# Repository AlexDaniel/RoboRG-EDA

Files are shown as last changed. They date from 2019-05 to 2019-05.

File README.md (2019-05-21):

# RoboRG-EDA

Schematics and PCB design files.



## License

    RoboRG is a low-cost camera motion control system.
    Copyright © 2018-2019
        Aleks-Daniel Jakimenko-Aleksejev <alex.jakimenko@gmail.com>

    This program is free software: you can redistribute it and/or modify
    it under the terms of the GNU Affero General Public License as
    published by the Free Software Foundation, either version 3 of the
    License, or (at your option) any later version.

    This program is distributed in the hope that it will be useful,
    but WITHOUT ANY WARRANTY; without even the implied warranty of
    MERCHANTABILITY or FITNESS FOR A PARTICULAR PURPOSE.  See the
    GNU Affero General Public License for more details.

    You should have received a copy of the GNU Affero General Public License
    along with this program.  If not, see <https://www.gnu.org/licenses/>.

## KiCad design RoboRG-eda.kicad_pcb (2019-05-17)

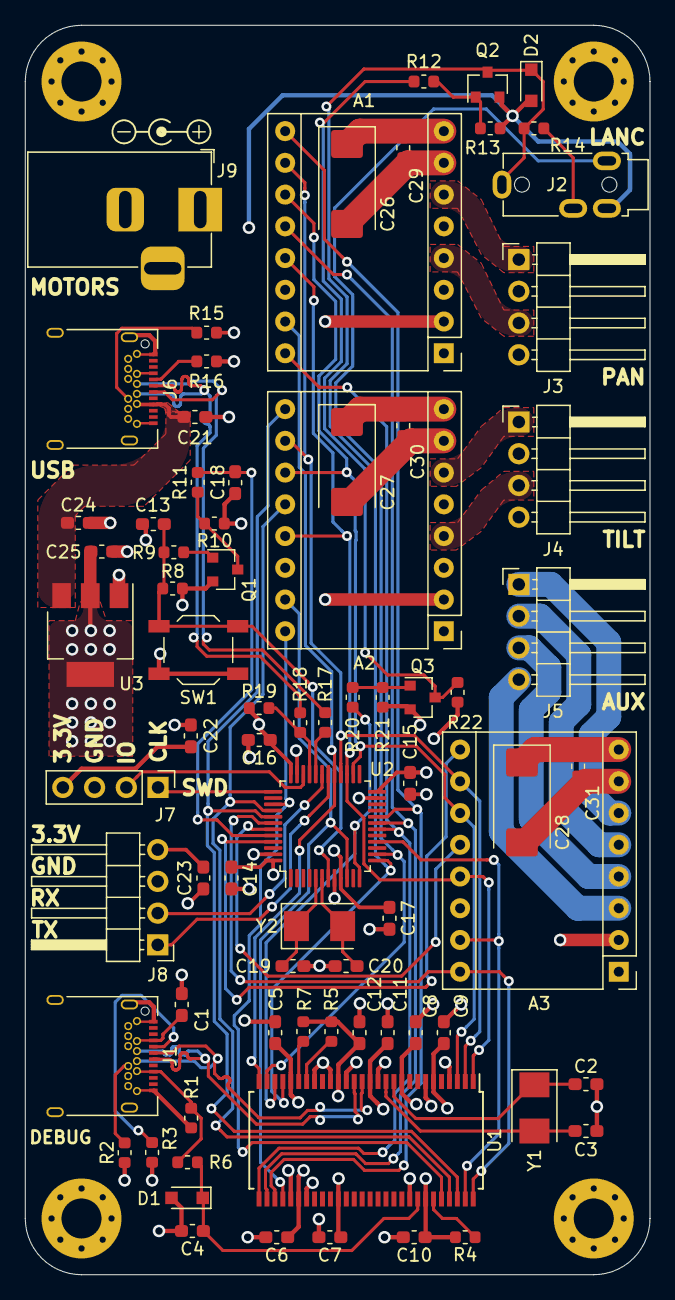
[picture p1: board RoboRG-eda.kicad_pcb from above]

Board: 4 copper layers, 50.0 x 100.0 mm, 80 parts (0 on the bottom side), 65 nets.

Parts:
A1: driver-pan (TMC2130); Pololu_Breakout-16_15.2x20.3mm
A2: driver-tilt (TMC2130); Pololu_Breakout-16_15.2x20.3mm
A3: driver-other (TMC2130); Pololu_Breakout-16_15.2x20.3mm
C1, C4, C5, C6, C7, C8, C9, C10, C11, C12, C13, C14, C15, C16, C17, C21, C22, C23, C24, C29, C30, C31: 100nF; C_0603_1608Metric_Pad1.05x0.95mm_HandSolder
C2, C3, C19, C20: 16pF; C_0603_1608Metric_Pad1.05x0.95mm_HandSolder
C18: 4.7µF; C_0603_1608Metric_Pad1.05x0.95mm_HandSolder
C25: 10µF; C_0603_1608Metric_Pad1.05x0.95mm_HandSolder
C26, C27, C28: 33µF; CP_EIA-7343-31_Kemet-D_Pad2.25x2.55mm_HandSolder
D1, D2: 3.3V; D_SOD-323_HandSoldering
H1, H2, H3, H4: MountingHole_Pad; MountingHole_3.2mm_M3_Pad_Via
J1, J6: USB_C_Receptacle_USB2.0; USB_C_Receptacle_Amphenol_12401548E4-2A
J2: AudioJack3_Switch; Jack_2.5mm_PJ-218A-SMT_Horizontal
J3: connector-pan; PinHeader_1x04_P2.54mm_Horizontal
J4: connector-tilt; PinHeader_1x04_P2.54mm_Horizontal
J5: connector-other; PinHeader_1x04_P2.54mm_Horizontal
J7: SWD; PinHeader_1x04_P2.54mm_Vertical
J8: USART; PinHeader_1x04_P2.54mm_Horizontal
J9: Barrel_Jack_Switch; BarrelJack_Horizontal
Q1: Q_PNP_BEC; SOT-23
Q2, Q3: Q_NPN_BEC; SOT-23
R1, R6, R9, R12, R20, R22: 1kΩ; R_0603_1608Metric
R2, R3, R15, R16: 5.1kΩ; R_0603_1608Metric
R4, R5, R7: 4.7kΩ; R_0603_1608Metric
R8, R10, R13, R21: 10kΩ; R_0603_1608Metric
R11: 33kΩ; R_0603_1608Metric
R14: 4.7KΩ; R_0603_1608Metric
R17, R18: 22Ω; R_0603_1608Metric
R19: 1.5kΩ; R_0603_1608Metric
SW1: SW_Push; SW_SPST_TL3342
U1: CY7C68013A-56PVX; SSOP-56_7.5x18.5mm_P0.635mm
U2: STM32F103C8Tx; LQFP-48_7x7mm_P0.5mm
U3: LD1117S33TR_SOT223; SOT-223-3_TabPin2
Y1: 24MHz; Crystal_SMD_5032-2Pin_5.0x3.2mm
Y2: 8MHz; Crystal_SMD_5032-2Pin_5.0x3.2mm

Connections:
+3V3: A1.2, A2.2, A3.2, C5.1, C6.1, C7.1, C8.1, C9.1, C10.1, C11.1, C12.1, C14.1, C15.1, C16.1, C17.1, C22.1, C23.1, C25.1, J7.4, J8.4, Q1.2, R4.1, R5.1, R7.1, R8.1, R19.1, R22.1, U1.6, U1.10, U1.14, U1.18, U1.24, U1.34, U1.39, U1.50, U2.9, U2.24, U2.36, U2.48, U3.2
+5V: C21.1, C24.1, J6.A4, J6.A9, J6.B4, J6.B9, U3.3
/Connections/SWD-CLK: J7.1, U2.37
/Connections/SWD-IO: J7.2, U2.34
/Connections/USART-RX: J8.2, U2.31
/Connections/USART-TX: J8.1, U2.30
/Connections/USB-D+: R18.1, R19.2, U2.33
/Connections/USB-D-: R17.1, U2.32
/Connections/USB-MCU-D+: J6.A6, J6.B6, R18.2
/Connections/USB-MCU-D-: J6.A7, J6.B7, R17.2
/Drivers/1A-other: A3.4, J5.3
/Drivers/1A-pan: A1.4, J3.3
/Drivers/1A-tilt: A2.4, J4.3
/Drivers/1B-other: A3.3, J5.4
/Drivers/1B-pan: A1.3, J3.4
/Drivers/1B-tilt: A2.3, J4.4
/Drivers/2A-other: A3.5, J5.2
/Drivers/2A-pan: A1.5, J3.2
/Drivers/2A-tilt: A2.5, J4.2
/Drivers/2B-other: A3.6, J5.1
/Drivers/2B-pan: A1.6, J3.1
/Drivers/2B-tilt: A2.6, J4.1
/Optional/5V-LA: C1.1, J1.A4, J1.A9, J1.B4, J1.B9, R1.1, R6.1
/Optional/USB-LA-D+: J1.A6, J1.B6, U1.15
/Optional/USB-LA-D-: J1.A7, J1.B7, U1.16
BOOT0: C18.1, R11.2, U2.44
GND: A1.1, A1.7, A2.1, A2.7, A3.1, A3.7, C1.2, C2.2, C3.2, C4.2, C5.2, C6.2, C7.2, C8.2, C9.2, C10.2, C11.2, C12.2, C13.2, C14.2, C15.2, C16.2, C17.2, C18.2, C19.2, C20.2, C21.2, C22.2, C23.2, C24.2, C25.2, C26.2, C27.2, C28.2, C29.2, C30.2, C31.2, D1.2, D2.2, H1.1, H2.1, H3.1, H4.1, J1.A1, J1.A12, J1.B1, J1.B12, J1.S1, J2.S, J6.A1, J6.A12, J6.B1, J6.B12, J6.S1, J7.3, J8.3, J9.2, J9.3, Q2.2, Q3.2, R1.2, R2.2, R3.2, R10.2, R13.2, R15.2, R16.2, R21.2, SW1.2, U1.4, U1.7, U1.13, U1.17, U1.19, U1.21, U1.33, U1.35, U1.48, U2.8, U2.23, U2.35, U2.47, U3.1
LANC-detect: J2.SN, U1.27, U2.14
LANC-in: D2.1, J2.T, Q2.3, R14.2, U1.25, U2.13
LANC-out: R20.2, U1.26, U2.12
NRST: C13.1, R8.2, R9.2, SW1.1, U2.7
unnamed: C2.1, U1.11, Y1.1
unnamed: C3.1, U1.12, Y1.2
unnamed: C4.1, D1.1, R6.2, U1.49
unnamed: C19.1, U2.5, Y2.1
unnamed: C20.1, U2.6, Y2.2
unnamed: J1.A5, R3.1
unnamed: J1.B5, R2.1
unnamed: J2.R, R14.1
unnamed: J6.A5, R16.1
unnamed: J6.B5, R15.1
unnamed: Q1.1, R9.1
unnamed: Q1.3, R10.1, R11.1
unnamed: Q2.1, R12.1, R13.1
unnamed: Q3.1, R20.1, R21.1
unnamed: Q3.3, R12.2, R22.2
unnamed: R4.2, U1.51
unnamed: R5.2, U1.22
unnamed: R7.2, U1.23
SPI-MISO: A1.13, A2.13, A3.13, U1.1, U2.27
SPI-MOSI: A1.10, A2.10, A3.10, U1.2, U2.28
SPI-SCK: A1.11, A2.11, A3.11, U1.3, U2.26
VDC: A1.8, A2.8, A3.8, C26.1, C27.1, C28.1, C29.1, C30.1, C31.1, J9.1
dir-other: A3.16, U1.56, U2.42
dir-pan: A1.16, U1.29, U2.18
dir-tilt: A2.16, U1.52, U2.39
enable-other: A3.9, U2.45
enable-pan: A1.9, U1.31, U2.20
enable-tilt: A2.9, U1.54, U2.41
select-other: A3.12, U2.43
select-pan: A1.12, U1.30, U2.19
select-tilt: A2.12, U1.53, U2.40
step-other: A3.15, U1.55, U2.16
step-pan: A1.15, U1.28, U2.29
step-tilt: A2.15, U1.32, U2.10

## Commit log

2019-05-10 First revision with all files
    The edit history is not quite there, but hopefully from now on all
    changes will be versioned.
    [RoboRG-eda.kicad_pcb, RoboRG-eda.sch, connections.sch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]
2019-05-11 Fix step/dir connections for AUX driver
    They were reversed.
    [RoboRG-eda.sch]
2019-05-11 Fix LANC pinout
    Ring and tip were reversed.
    [lanc.sch]
2019-05-12 Add inverter on LANC-out
    So that it is possible to use hardware UART for pushing the bytes
    out. Note that it is known to be less reliable than bit-banging, but
    adding it anyway for completeness.
    [lanc.sch, mcu.sch]
2019-05-13 Propagate all fixes to the PCB
    Also fix some footprints along the way.
    [RoboRG-eda.kicad_pcb, lanc.sch, mechanical.sch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]
2019-05-13 Proper page settings for the PCB
    Also bump the version to 1.0.1.
    [RoboRG-eda.kicad_pcb, RoboRG-eda.sch, connections.sch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]
2019-05-16 Flip D+/D- of the LA
    Oops!
    [RoboRG-eda.kicad_pcb, optional.sch]
2019-05-16 Bump version
    [RoboRG-eda.kicad_pcb, RoboRG-eda.sch, connections.sch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]
2019-05-17 Reorder sheets
    So that the PDF plot is nice.
    [RoboRG-eda.sch, connections.sch, drivers.sch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]
2019-05-17 Make things more centered
    [connections.sch, mechanical.sch, optional.sch]
2019-05-17 Fix version number on the silkscreen
    [RoboRG-eda.kicad_pcb]
2019-05-17 Tweak PDF generation
    [RoboRG-eda.kicad_pcb]

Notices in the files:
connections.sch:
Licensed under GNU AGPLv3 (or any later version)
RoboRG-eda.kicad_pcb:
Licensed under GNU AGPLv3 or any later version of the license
